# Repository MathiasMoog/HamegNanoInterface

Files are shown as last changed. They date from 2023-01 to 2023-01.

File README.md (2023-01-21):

# Serial Interface for HAMEG HM205-3 Analog/Digital Oscilloscope

I still use my old HAMEG HM205-3 scope. It has a socket for an digital interface, but the interface itself was missing when I got the scope. Here is my solution, a serial interface based on an Arduino Nano.

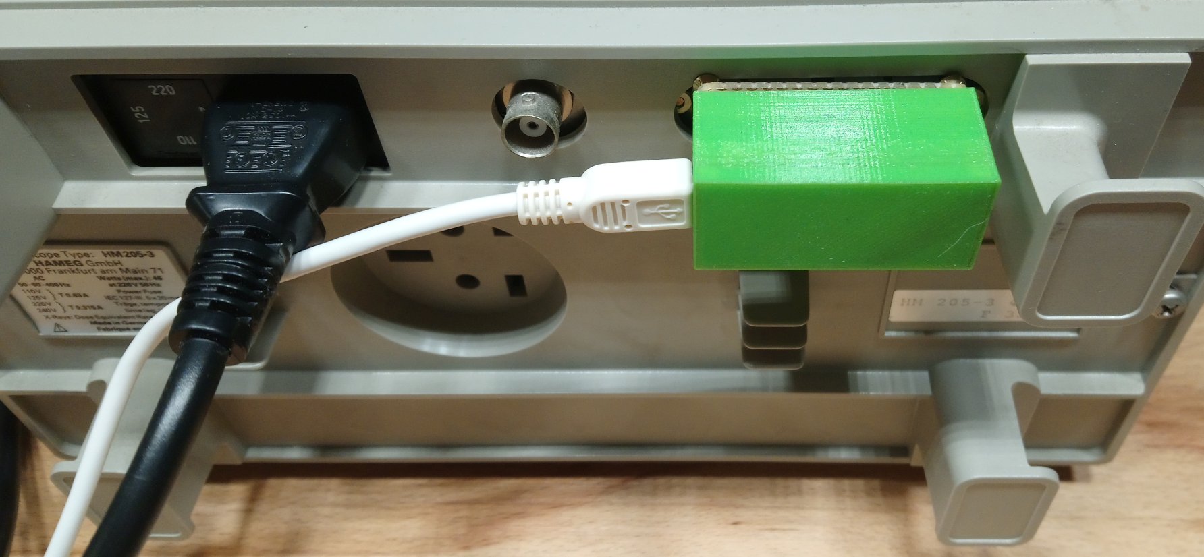
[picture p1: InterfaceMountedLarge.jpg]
Mounted interface


**Warning: This interface does not provide galvanic isolation!**

**No Waranty. Everything works fine for me. Please check your scope manual if you want to use my Interface with a different scope.**

## Electical Connections

The Arduino Nano is mounted on a small double layer matrix board together with the 2 x 13 female header for the  connection to the scope.

There is no 8 bit parallel port available at the Arduino Nano with the ATMEGA 328 chip. I splitted it in two 4 bit reads on Port B (lower nibble) and port D (upper nibble). Details in the table below.

### Connection table between Scope and Nano
  
    Signal  Port  Arduino HM 205  pinMode  Hameg notation   Connection   Remarks
    D0      PB0   8       3       Input                     Direct
    D1      PB1   9       4       Input                     Direct
    D2      PB2   10      5       Input                     Direct
    D3      PB3   11      6       Input                     Direct
    D4      PD4   4       7       Input                     Direct
    D5      PD5   5       8       Input                     Direct
    D6      PD6   6       9       Input                     Direct
    D7      PD7   7       10      Input                     Direct
  
    CHSEL   PC5   A5      17      In/Output                 330 Ohm       1
    CLR     PC0   A4      18      Output    RESAZ           330 Ohm
    CLK     PC3   A3      19      Output    CLAC            330 Ohm
    SQR     PC2   A2      20      Output                    330 Ohm       1
    TE      PC1   A1      22      Input     LSING           330 Ohm       1
    Reset   PC0   A0      23      Output    CLRSING         330 Ohm       1
  
    GND           GND     1,25,26  
    5 V           5 V     11                                Diode, anode hameg -> kathode Arduino   
	
Remark 1: These signals are not used at the moment. If I find some time I will extend it.
  
I soldered resistors for all connections to port C since some of the signals might be input or output.

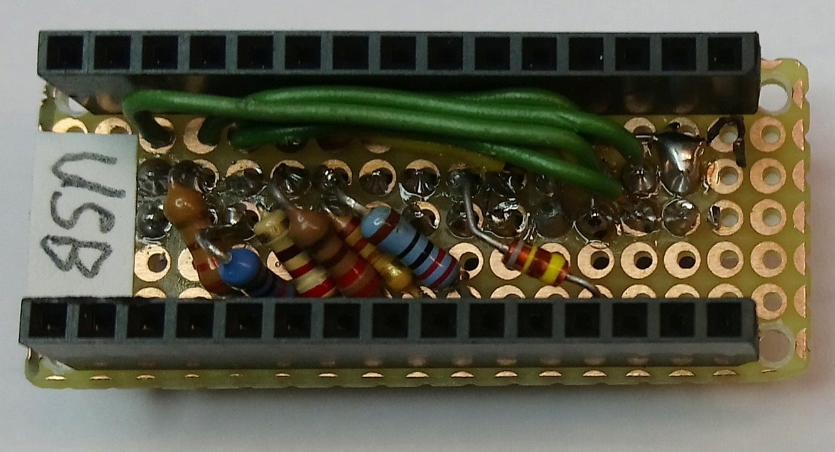
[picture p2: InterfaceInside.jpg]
solderd resistors and connections

   
The Arduino Nano is powered by the USB port, or from the scope via the diode if there is no USB connection.

## 3D printed housing 

Design with OpenScad in HamegNanoCover.scad.

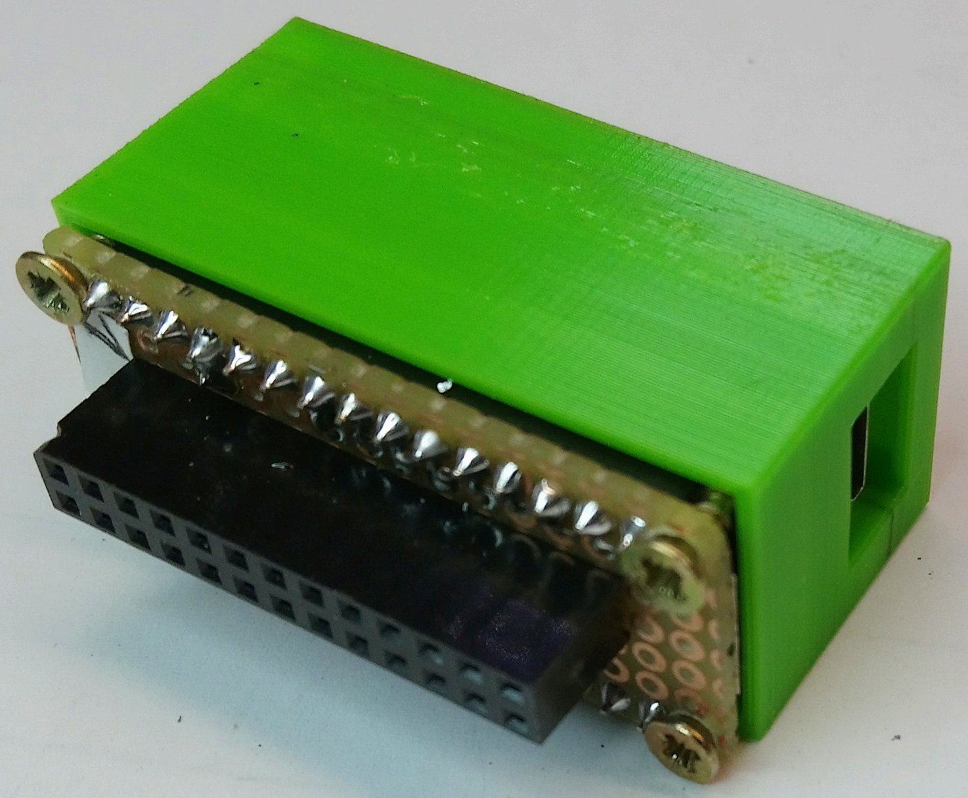
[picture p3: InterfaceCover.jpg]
3D printed Cover


## Arduino Sketch

Use the Arduin IDE to compile and upload the sketch. If you like

## Serial Protocoll

The Nano accepts the following commands:
- a  Ascii output mode, human readable output
- b  Binary output mode, faster for M2M communication
- s  status, printe status of all signals at port C, see below
- r1  readout, one channel, 2048 Points
- r2  readout, one channel, 2 x 2048 Points

In ascii mode, on decimal number per line, in binary mode block with 2048 or 4096 raw bytes.

You might use my Octave Code for communication, see my OctaveLab repository at GitHub, https://github.com/MathiasMoog/OctaveLab

## Literature

- Hameg 205-3 manual
- Hendrik Klassssen, Die Symbiose, Atari ST als Controller für Hameg-Oszilloskope, Elrad 10/91, S. 41 ff.

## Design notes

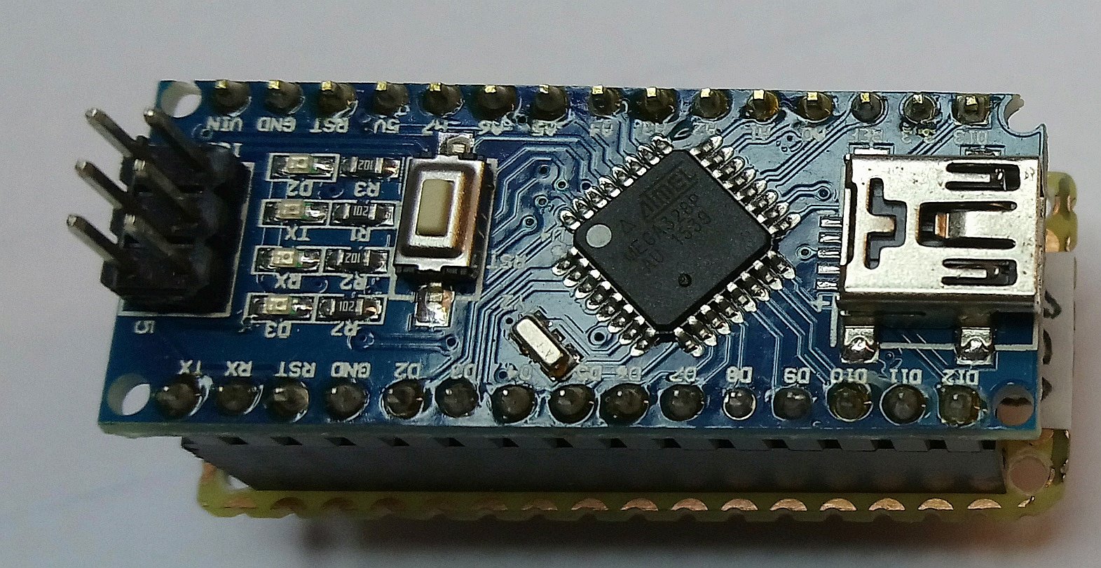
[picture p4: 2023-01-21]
InterfaceNano.jpg

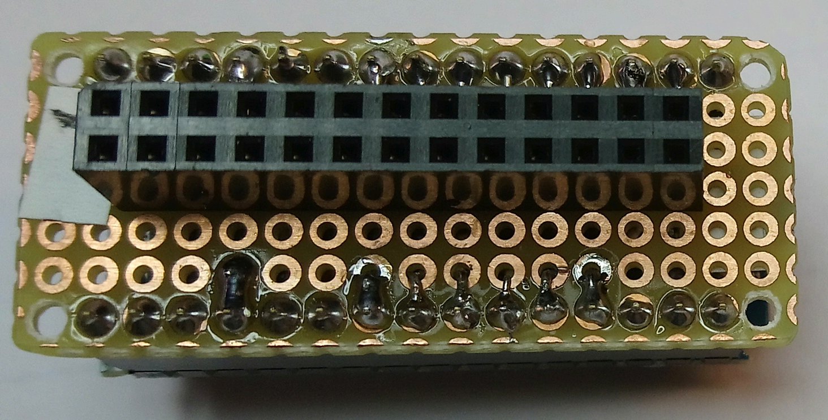
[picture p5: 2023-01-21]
InterfaceSocket.jpg

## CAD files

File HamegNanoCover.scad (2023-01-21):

/* Housing for the Arduino Nano Interface 
 *  See readme.md for further details
 *
 * Print with PLA, perhaps support for USB socket hole. Use 40 % infill (screw domes).
 *
 * Copyright, 2023, Mathias Moog, Deutschland, CC-BY-NC-SA
 */
 
$fn=30;
 
// Wall Thickness
w = 1.2;
// Space arround Nano
s = 0.3;
// ISP heigt
h_isp = 8;
// Top of Nano PCB to top of matrix board
h_nm  = 12.5;

// Diameter for the screw holes, arduino 1.8 mm
d = 1.4;
// You need 4 screws with 1.6 mm diameter and 20 mm length

// USB Heigt
u_h = 4;
// USB Width
u_w = 8;
// Space arround USB
u_s = 2;

// Arduino nano dimenisons from Datasheet

// length
n_l  = 43.2;
// hole distance in length direction
n_hl = 40.64;

// width
n_w  = 18;
n_hw = 15.24;

difference() {
  // complet material
  cube([n_w+2*(s+w),n_l+2*(s+w),h_isp+h_nm+s+w]);
  // Below Arduino
  translate([w,w,h_isp+s+w]) cube([n_w+2*s,n_l+2*s,h_nm+s]);
  // Arduion, without area for mounting hole
  // widht, a bit more for mountings
  wm=3;
  translate([w+wm+s,w,w])
    cube([n_w-2*wm,n_l+2*s,h_isp+2*s]);
  // length a bit less
  wl=2.54;
  translate([w,w+wl+s,w])
    cube([n_w+2*s,n_l-2*wl,h_isp+2*s]);
  // Screw holes
  h_w = w+s+(n_w-n_hw)/2;
  h_l = w+s+(n_l-n_hl)/2;
  translate([h_w,h_l,w])
    cylinder(d=d,h=h_isp+2*s);
  translate([h_w+n_hw,h_l,w])
    cylinder(d=d,h=h_isp+2*s);
  translate([h_w,h_l+n_hl,w])
    cylinder(d=d,h=h_isp+2*s);
  translate([h_w+n_hw,h_l+n_hl,w])
    cylinder(d=d,h=h_isp+2*s);
  // USB Hole
  u_W = w+s+(n_w-u_w)/2-u_s;
  u_H = w+s+h_isp-u_h-u_s;
  translate([u_W,-w,u_H])
    cube([u_w+2*u_s,3*w,u_h+2*u_s]); 
}  

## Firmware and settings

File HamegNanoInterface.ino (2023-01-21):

/* Hameg HM 205-3 Interface with an Arduino Nano.
 *
 *  Arduino Nano Interface for my Hameg 205-3 Scope. 
 *
 *  See readme.md for further details
 *
 *  Copyright, 2023, Mathias Moog, Deutschland, CC-BY-NC-SA
 */

// -------------------------------------------------------------------------------
// Pin Mappings

// Data Pins, in right order
const byte Dpins[8] = { 8, 9, 10, 11, 4, 5, 6, 7 };
// Other Pins
#define CHSEL A5
#define CLR A4
#define CLK A3
#define SQR A2
#define TE A1
#define RESET A0

// -------------------------------------------------------------------------------
// Ascii or binary protocoll, here default settings, change with a = ascii and b = binary

boolean asciiOutput = true;

// -------------------------------------------------------------------------------
// Inline helper functions

// parallel read data pins, see table above
inline byte parallelRead() {
  return (PINB & 0x0f) | (PIND & 0xf0);
}

// set CLR
inline void clr(const boolean v) {
  digitalWrite(CLR, v);
}

// set CLK
inline void clk(const boolean v) {
  digitalWrite(CLK, v);
}

// Set SQR
inline void sqr(const boolean v) {
  digitalWrite(SQR, v);
}

// Set TE
inline boolean te() {
  return digitalRead(TE);
}

// disable all outputs, set to input
inline void disableOutput() {
  pinMode(CLR, INPUT);
  pinMode(CLK, INPUT);
  pinMode(SQR, INPUT);
  // Momentan noch nicht genutzt, erst mal als Input
  pinMode(CHSEL, INPUT);
  pinMode(RESET, INPUT);
  // Normale Inputs ebenfalls setzen
  pinMode(TE, INPUT);
}

// enable all outputs, set to output and to default value
inline void enableOutput() {
  pinMode(CLR, OUTPUT);
  clr(HIGH);
  pinMode(CLK, OUTPUT);
  clk(LOW);
  pinMode(SQR, OUTPUT);
  sqr(LOW);
}

// -------------------------------------------------------------------------------
// Setup

void setup() {
  Serial.begin(115200);
  if (asciiOutput) {
    Serial.println("HM205-3 Scope Interface");
    Serial.println("Activate 'STOR' befor reading and data.");
  }

  // Configure pins for parallel input
  for (byte i = 0; i < 8; i++) pinMode(Dpins[i], INPUT);
  // Configure remaining pins, Port C, see above, set to input per default
  disableOutput();
  // initialize digital pin LED_BUILTIN as an output.
  pinMode(LED_BUILTIN, OUTPUT);
}

// -------------------------------------------------------------------------------
// Loop

void loop() {
  // Wait for command
  if (Serial.available()) {
    char command = Serial.read();
    // command switch
    switch (command) {
      case 'a':  // Switch to ascii output
        asciiOutput = true;
        break;
      case 'b':  // Switch to binary output
        asciiOutput = false;
        break;
      case 'r':  // Read Data
        readData(Serial.parseInt());
        break;
      case 's':  // Status
        {
          const byte s = PINC;
          if (asciiOutput) {
            Serial.print("Status ");
            Serial.println(s, BIN);
            Serial.print(", CHSEL ");
            Serial.print(bitRead(s, 5));
            Serial.print(", CLR ");
            Serial.print(bitRead(s, 4));
            Serial.print(", CLK ");
            Serial.print(bitRead(s, 3));
            Serial.print(", SQR ");
            Serial.print(bitRead(s, 2));
            Serial.print(", TE ");
            Serial.print(bitRead(s, 1));
            Serial.print(", TE (digitalRead) ");
            Serial.print(te());
            Serial.print(", RESET ");
            Serial.print(bitRead(s, 0));
            Serial.println();
            Serial.print("Value ");
            Serial.println(parallelRead());
          } else {
            Serial.write(s);
          }
        }
        break;
    };  // End Switch
  }     // end if
}  // End loop

// -------------------------------------------------------------------------------
// Read Data

/* Read one or two channels
 *  HM 205-3 has 2048 bytes per channel.
 *  If only one channel is active and two channels should be read, the first channel ist repeated.
 */
void readData(byte channel) {
  digitalWrite(LED_BUILTIN, HIGH);  // turn the LED on (HIGH is the voltage level)
  if (asciiOutput) {
    Serial.print("Start Read, channel = ");
    Serial.println(channel);
  }
  const int n = (channel == 1) ? 2048 : 4096;  // Number of bytes to read
  enableOutput();
  delay(1);
  // Set SQR to HIGH level, want to read ...
  sqr(HIGH);
  delayMicroseconds(10);
  // Reset Counter
  clr(LOW);
  delayMicroseconds(10);
  clr(HIGH);
  delayMicroseconds(5);
  // Read Data and Output to Serial Port
  for (int i = 0; i < n; i++) {
    // todo check clock defintion and timing
    clk(HIGH);
    delayMicroseconds(1);
    const uint8_t d = parallelRead();
    if (asciiOutput) {
      Serial.println(d, DEC);
    } else {
      Serial.write(d);
    }
    clk(LOW);
    delayMicroseconds(1);
  }
  // Set SQR back to LOW
  sqr(LOW);
  delay(1);
  // disable all outputs, set to input
  disableOutput();
  digitalWrite(LED_BUILTIN, LOW);  // turn the LED off by making the voltage LOW
}  // End of readData
